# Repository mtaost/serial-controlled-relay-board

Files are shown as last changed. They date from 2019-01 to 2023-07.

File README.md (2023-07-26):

# Serial Controlled Relay Board
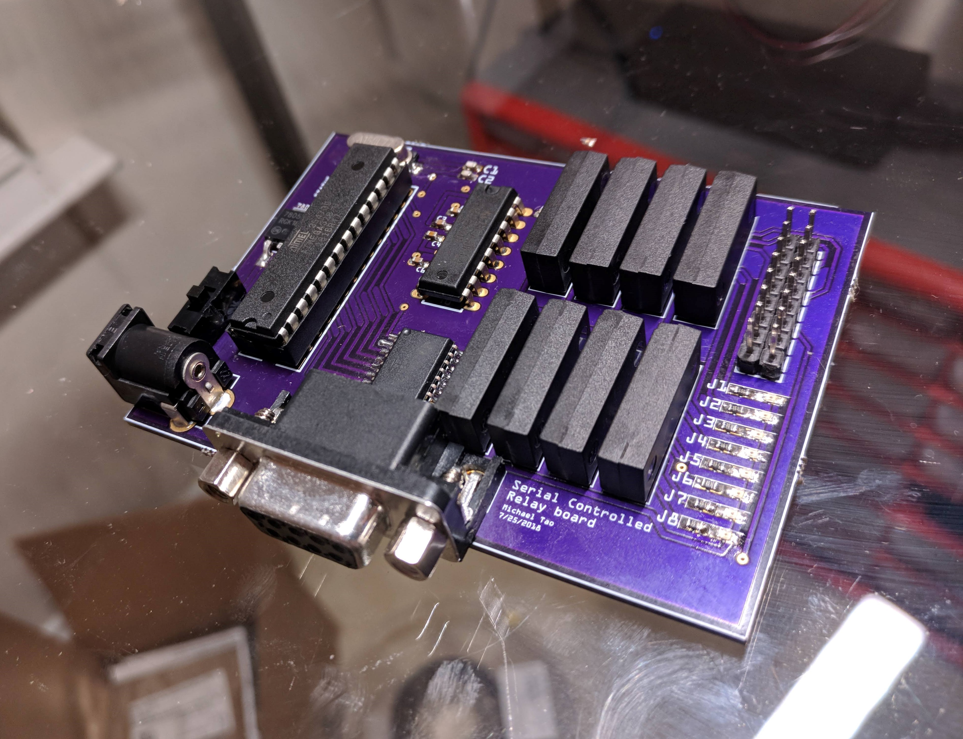
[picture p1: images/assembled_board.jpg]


This device is a command line controlled device capable of controlling 8 low current reed relays. This was a commissioned project which was meant to help with testing of computer systems which frequently needed their boot configurations switched through hardware jumpers. The normal procedure involved shutting down the system remotely, then walking over to the lab to remove the system from the chassis and manually setting jumpers which looked something like this: 



Doing this not only was time consuming, but also introduced the system to risk of damage from physical wear and tear, and ESD dangers. 
With the SCRB, one can remotely control the state of whatever jumpers are on the board through a command line interface. For example: 

    $ Serial Relay Controller Ready
    
    $ status
	    J1:		OFF
	    J2:		OFF
	    J3:		OFF
	    J4:		OFF
	    J5:		OFF
	    J6:		OFF
	    J7:		OFF
	    J8:		OFF
	    
	$ set J1 on
	J1: OFF -> ON
After this series of commands, the jumper in position J1 will now be connected, simulating a connected jumper. The board also supports renaming jumpers: 

    $ rename J1 write_protect
    J1 renamed to: write_protect
    $ status
    	write_protect:		ON
	    J2:		OFF
	    J3:		OFF
	    J4:		OFF
	    J5:		OFF
	    J6:		OFF
	    J7:		OFF
	    J8:		OFF

This could also be used for other, low current/voltage switching applications. 
## Circuit design
The SCRB uses a simple ATmega 328PU MCU as its brains. This is the same microprocessor used on the Arduino Uno which I happened to have a lot of which made it easy to prototype and test. Communication with the serial connection is managed through a MAX232 level converter which is necessary to lower the higher voltage levels of the RS232 standard (-13 to +13 volts) to a more TTL friendly 0-5v. To handle the switching of the relays, a Darlington transistor array ensures that the microprocessor is not damaged by the inductive kickback of the relays (however small it might be). 
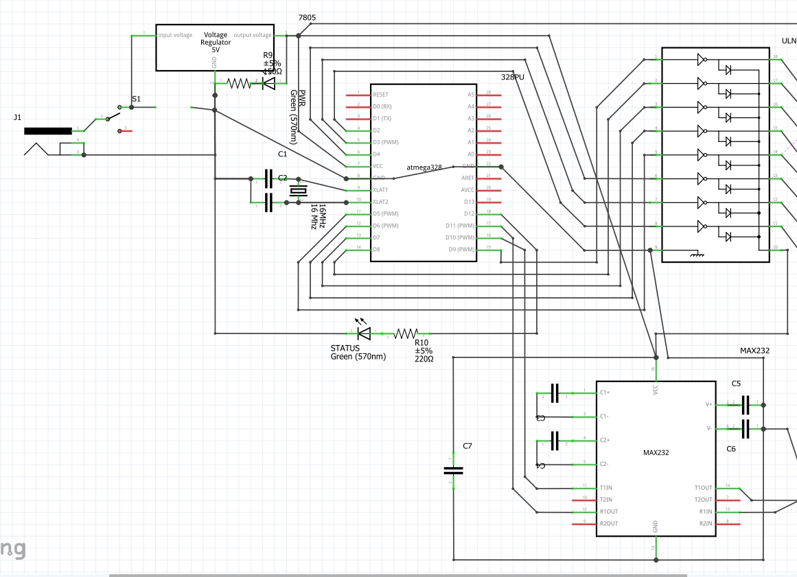
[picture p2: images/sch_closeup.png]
Schematic of processing side of SCRB


The relays used are 500mAh, 200VDC reed relays. In their application as jumper connectors, they really only need to switch 3.3VDC and negligible current but these were the most suitable relays I could find. An array of LEDs lets you know when each relay is working. 

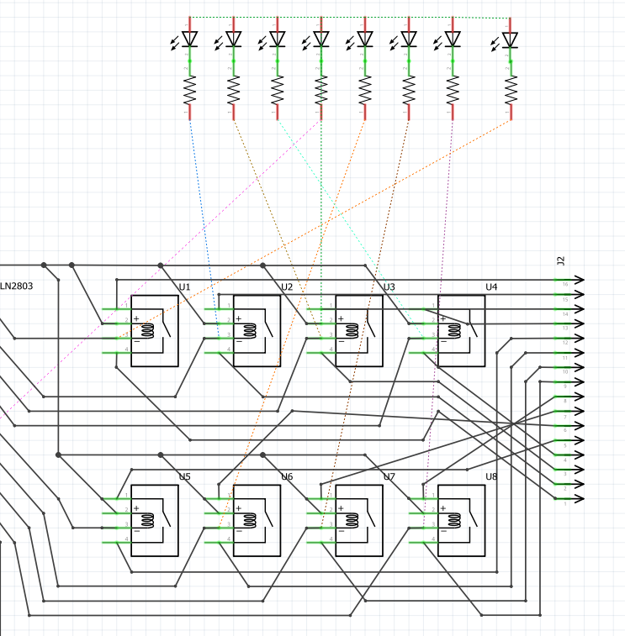
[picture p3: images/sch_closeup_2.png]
Schematic of relay side of SCRB


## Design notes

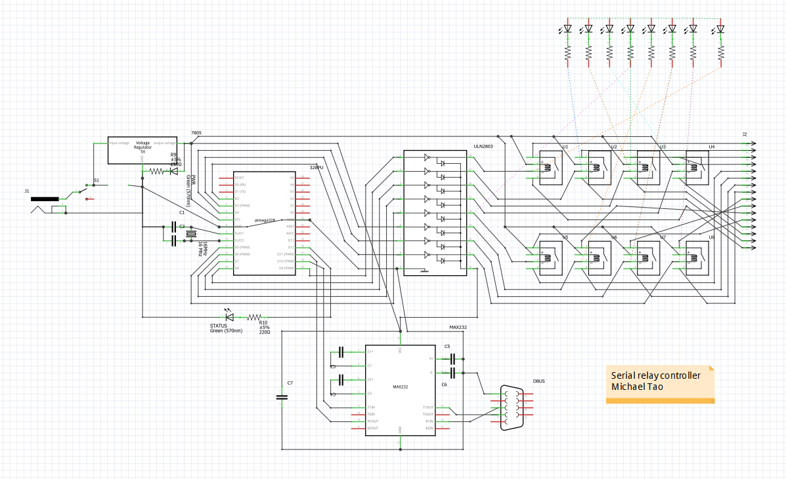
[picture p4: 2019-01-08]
images/sch_overview.png

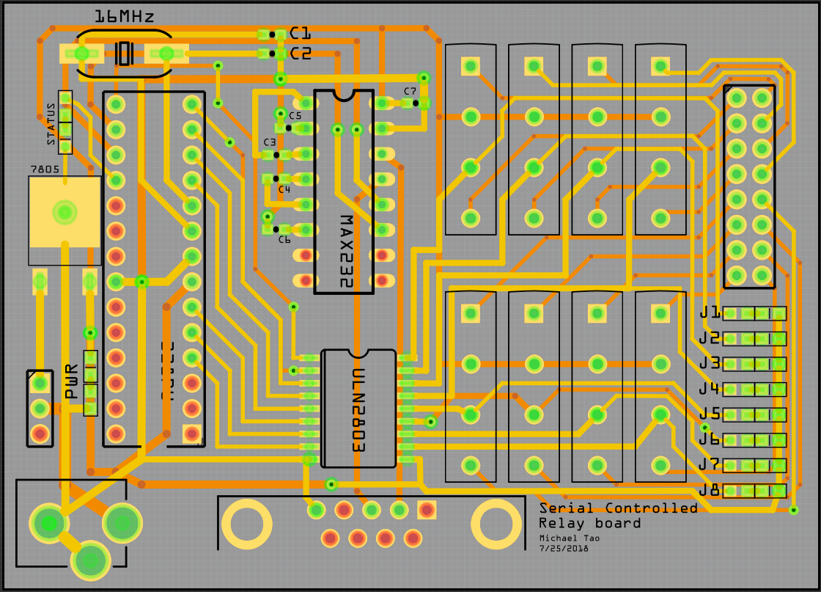
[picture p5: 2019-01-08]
images/pcb_overview.png

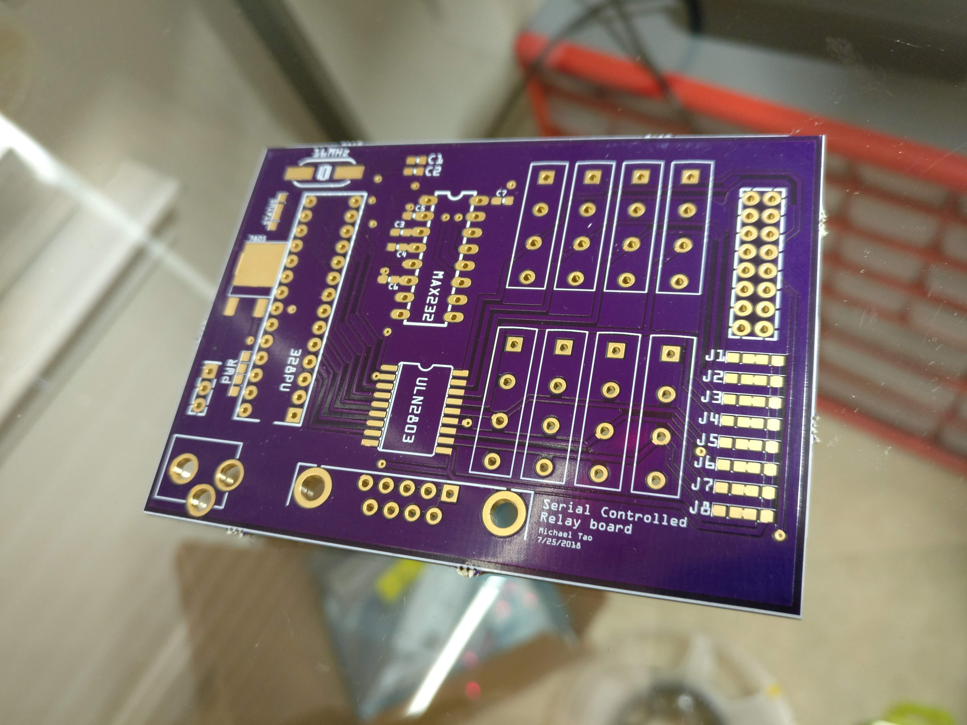
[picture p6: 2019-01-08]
images/pcb_top.jpg

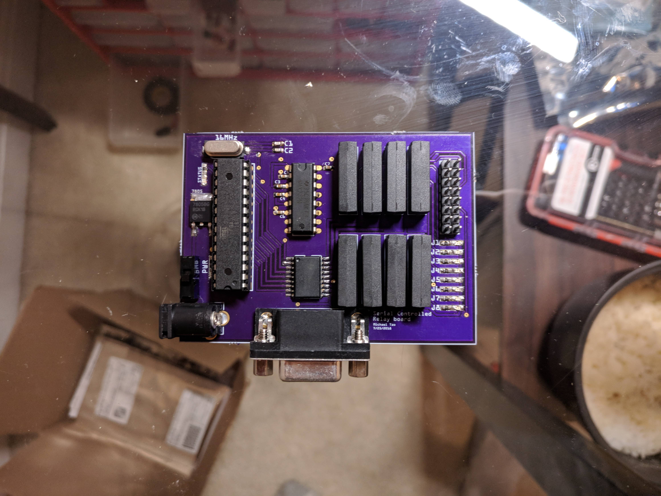
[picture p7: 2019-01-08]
images/top_view.jpg

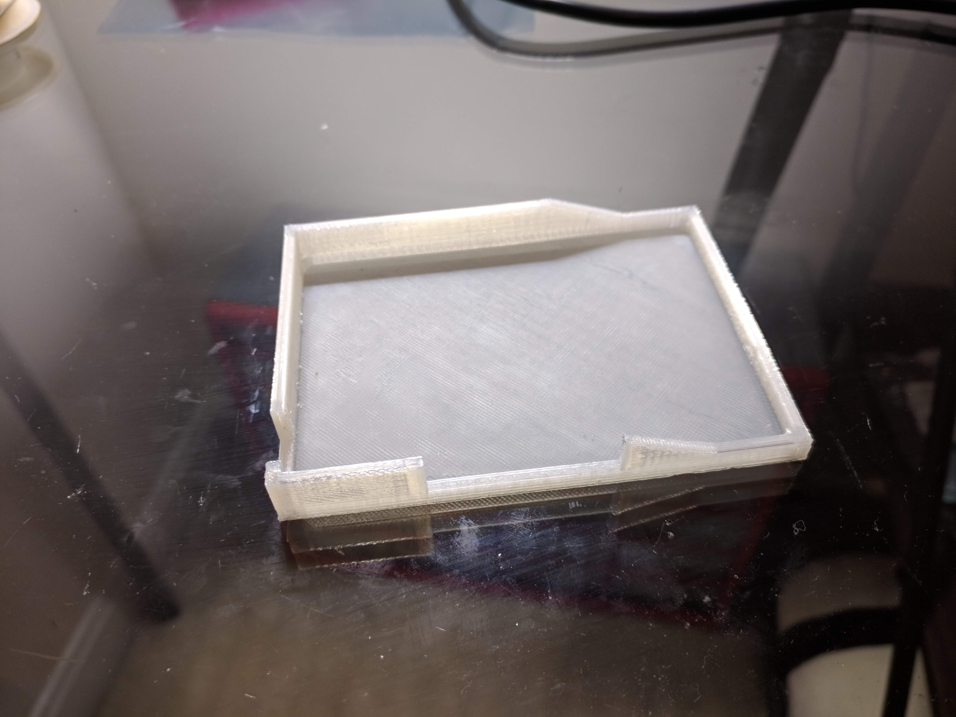
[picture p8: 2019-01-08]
images/pla_enclosure.jpg

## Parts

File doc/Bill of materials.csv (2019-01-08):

Manufacturer | Digi-Key Part Number | Customer Reference | Quantity | Unit Price | Extended Price | Description
Panasonic Electronic Components | P150HCT-ND | LED resistors | 8 | 0.1 | $0.80 | RES SMD 150 OHM 1% 1/10W 0603
ON Semiconductor | MC7805BDTRKGOSCT-ND | 5V power regulator | 1 | 0.64 | $0.64 | IC REG LINEAR 5V 1A DPAK
On Shore Technology Inc. | ED3050-5-ND | MCU socket | 1 | 0.34 | $0.34 | CONN IC DIP SOCKET 28POS TIN
Abracon LLC | 535-10226-1-ND | MCU Crystal | 1 | 0.27 | $0.27 | CRYSTAL 16.0000MHZ 18PF SMD
E-Switch | EG1903-ND | Power switch | 1 | 0.61 | $0.61 | SWITCH SLIDE SPDT 200MA 30V
CUI Inc. | CP-002A-ND | Power jack | 1 | 0.63 | $0.63 | CONN PWR JACK 2X5.5MM SOLDER
Murata Electronics North America | 490-1411-1-ND |  | 2 | 0.11 | $0.22 | CAP CER 22PF 50V C0G/NP0 0603
Texas Instruments | 296-15777-1-ND |  | 1 | 1.53 | $1.53 | TRANS 8NPN DARL 50V 0.5A 18SO
Coto Technology | 306-1063-ND | Reed relays | 8 | 1.43 | $11.44 | RELAY REED SPST 500MA 5V
Microchip Technology | ATMEGA328-PU-ND |  | 1 | 1.96 | $1.96 | IC MCU 8BIT 32KB FLASH 28DIP
Texas Instruments | 296-1402-5-ND |  | 1 | 1.49 | $1.49 | IC DUAL EIA-232 DRVR/RCVR 16-DIP
Assmann WSW Components | AE10921-ND |  | 1 | 0.77 | $0.77 | CONN D-SUB RCPT 9POS R/A SOLDER
Lite-On Inc. | 160-1446-1-ND |  | 8 | 0.29 | $2.32 | LED GREEN CLEAR SMD
Samsung Electro-Mechanics | 1276-1102-1-ND |  | 4 | 0.1 | $0.40 | CAP CER 1UF 25V X5R 0603

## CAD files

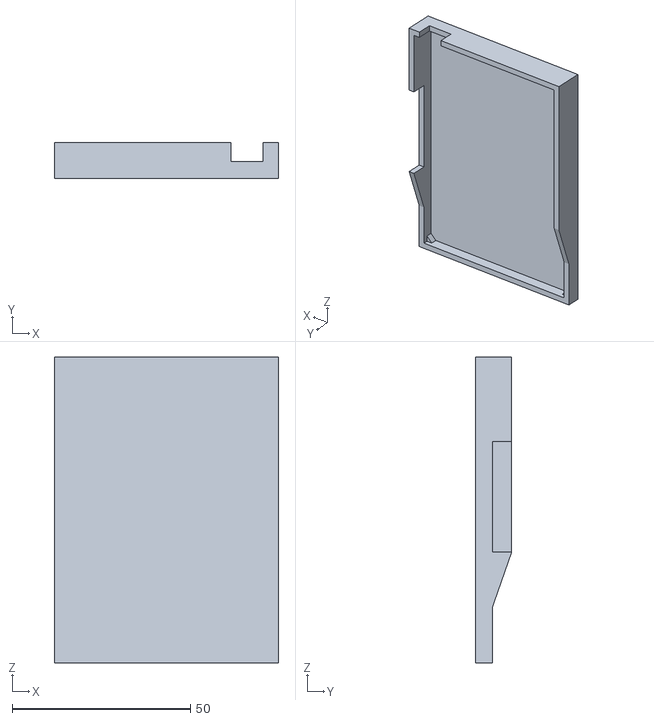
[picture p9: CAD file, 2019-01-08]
3D_print_enclosure/Enclosure.stl
62.8 x 10.2 x 85.8

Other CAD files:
3D_print_enclosure/Enclosure.ipt

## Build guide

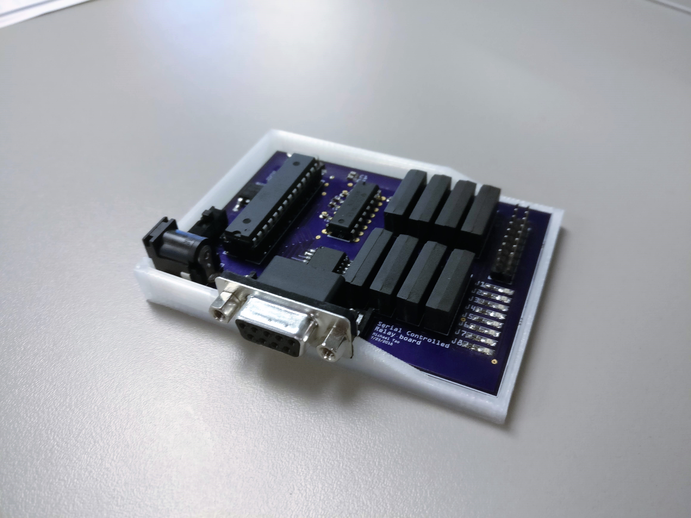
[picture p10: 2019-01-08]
images/assembled_board_in_enclosure.jpg

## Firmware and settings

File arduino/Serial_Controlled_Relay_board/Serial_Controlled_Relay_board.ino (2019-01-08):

/*
   Serial Relay Controller
   Author: Michael Tao
   Date: 8/9/2018

   Credit to https://github.com/kroimon/Arduino-SerialCommand for inspiration for serial command line interpreter
*/

#include <SoftwareSerial.h>

#define NUM_COMMANDS 5
#define BUFFER_SIZE 64
#define MAX_COMMAND_SIZE 16
#define MAX_JUMPER_NAME_SIZE 16
#define NUM_JUMPERS 8
#define BAUD_RATE 115200
#define PROMPT "# "
#define DELIMINATOR " "

// Pin definitions
// These are specific to how the board is routed so they're here for reference
#define J1_PIN 9
#define J2_PIN 8
#define J3_PIN 7
#define J4_PIN 6
#define J5_PIN 5
#define J6_PIN 4
#define J7_PIN 3
#define J8_PIN 2
#define TX 10
#define RX 11
#define STATUS_LED 12

SoftwareSerial softSerial = SoftwareSerial(RX, TX);
// Buffer for storing input so far
char buffer[BUFFER_SIZE];
int buffPos = 0;

// Counter to newest position in command list
int numCommands = 0;

// Struct to keep track of command names and their function call
struct Command {
  char name[MAX_COMMAND_SIZE];
  void (*function)();
};
Command commandList[NUM_COMMANDS];

// Struct to keep track of jumper names and their state
struct Jumper {
  char name[MAX_JUMPER_NAME_SIZE];
  int pin;
  boolean state = false; // true for on, false for off
};
Jumper jumperList[NUM_JUMPERS];

// Flag to keep track of whether we've sent the prompt or not
boolean prompt_sent;

// Terminal character (generally set to \r)
char term;

// Something for strtok_r to remember what it last tokenized. See strtok_r documentation for details
char* last;


void setup() {
  pinMode(STATUS_LED, OUTPUT);
  pinMode(J1_PIN, OUTPUT);
  pinMode(J2_PIN, OUTPUT);
  pinMode(J3_PIN, OUTPUT);
  pinMode(J4_PIN, OUTPUT);
  pinMode(J5_PIN, OUTPUT);
  pinMode(J6_PIN, OUTPUT);
  pinMode(J7_PIN, OUTPUT);
  pinMode(J8_PIN, OUTPUT);

  softSerial.begin(BAUD_RATE);

  // Setup callbacks for commands
  addCommand("help", help);
  addCommand("set", set);
  addCommand("status", status);
  addCommand("rename", rename);
  addCommand("reset", reset);

  softSerial.println('\f');
  softSerial.println("Serial Relay Controller ready");
  blink(3);

  // Set jumper values to their defaults
  defaultJumperInit();

  // Establish the buffer and other strings reader needs to function
  initReader();
}

// In the loop, we send the prompt if it hasn't been sent, and then just call readSerial() to wait for user input
void loop() {
  if (!prompt_sent) {
    softSerial.print(PROMPT);
    prompt_sent = true;
    blink(1);
  }
  readSerial();
}


// Just prints user manual
void help() {
  softSerial.println("Available commands: ");
  softSerial.println("   set jumper_name|all {on|off}");
  softSerial.println("       Sets jumper with name 'jumper_name' on or off. If jumper name is 'all', will set all jumpers.\n");
  softSerial.println("   status [jumper_name]");
  softSerial.println("       Shows whether jumper is on or off. If no jumper or 'all' is provided, will display all jumper statuses\n");
  softSerial.println("   rename old_name new_name");
  softSerial.println("       Renames a jumper. Cannot use an existing name or 'all'\n");
  softSerial.println("   reset");
  softSerial.println("       Resets jumper names back to defaults. Sets all jumpers to off.\n");
  softSerial.println("   help");
  softSerial.println("       Displays this help dialogue.");
}


// Blink method for visual confirmation that things are working. Not really used though
void blink(int i) {
  while (i > 0) {
    digitalWrite(STATUS_LED, HIGH);
    delay(100);
    digitalWrite(STATUS_LED, LOW);
    delay(100);
    i--;
  }
}

// Sets a jumper to on or off. This is called after the "set" part of the command has been consumed, so jumperName and state are obtained
// by calling nextToken() which will consume the next two tokens (if there are any)
void set() {
  char *jumperName = nextToken();
  char *state = nextToken();
  int jumper_index;
  boolean setTo;
  boolean lastState;

  if (jumperName == NULL) {
    softSerial.println("Missing jumper");
    softSerial.println("Syntax: set jumper {on/off}");
    softSerial.println("        set all    {on/off}");
    return;
  }

  if (state == NULL) {
    softSerial.println("Please specify a value for state");
    softSerial.println("Syntax: set jumper {on/off}");
    softSerial.println("        set all    {on/off}");
    return;
  }

  if (strcmp(state, "on") == 0) {
    setTo = true;
  }
  else if (strcmp(state, "off") == 0) {
    setTo = false;
  }
  // If we don't match on or off, invalid state
  else {
    softSerial.println("Please specify either 'on' or 'off'");
    return;
  }

  // Get the index of the jumper we're looking for
  jumper_index = findJumper(jumperName);

  // If we don't find the jumper name
  if (jumper_index == -1) {
    // If jumper name is all (case insensitive), loop through all jumpers and set them
    if (strcmp(strlwr(jumperName), "all") == 0) {
      for (int i = 0; i < NUM_JUMPERS; i++) {
        Jumper j = jumperList[i];
        lastState = j.state;
        j.state = setTo;
        jumperList[i] = j;

        softSerial.print(j.name);
        softSerial.print("\t: ");
        lastState ? softSerial.print("ON ") : softSerial.print("OFF");
        softSerial.print(" -> ");
        setTo ? softSerial.println("ON") : softSerial.println("OFF");

        updateState(i);
      }
    }

    // Otherwise for jumper_index == -1, jumper is invalid
    else {
      softSerial.print(jumperName);
      softSerial.println(" is not a valid jumper");
      softSerial.println("Use 'status' for a list of valid jumpers");
    }
  }

  // If we have a jumper index, set the jumper
  else {
    Jumper j = jumperList[jumper_index];
    lastState = j.state;
    j.state = setTo;
    jumperList[jumper_index] = j;

    softSerial.print(jumperName);
    softSerial.print(": ");
    lastState ? softSerial.print("ON") : softSerial.print("OFF");
    softSerial.print(" -> ");
    setTo ? softSerial.println("ON") : softSerial.println("OFF");

    updateState(jumper_index);
  }
}

// Renames a jumper, cannot name a jumper any variation of 'all' to avoid confusion with the keyword used in 'set all on/off'
void rename() {
  char *oldName = nextToken();
  char *newName = nextToken();
  int jumperIndex;

  if (oldName == NULL) {
    softSerial.println("Missing jumper_name");
    softSerial.println("Syntax: rename jumper_name new_name");
    return;
  }
  if (newName == NULL) {
    softSerial.println("Missing new_name");
    softSerial.println("Syntax: rename jumper_name new_name");
    return;
  }

  // Do not allow a jumper to be named "ALL"
  if (strcmp(newName, "all") == 0) {
    softSerial.println("Jumper cannot be named 'all'");
    return;
  }

  jumperIndex = findJumper(oldName);

  // Invalid jumper option
  if (jumperIndex == -1) {
    softSerial.print(oldName);
    softSerial.println(" is not a valid jumper");
  }

  // New jumper name already exists
  else if (findJumper(newName) != -1) {
    softSerial.print(newName);
    softSerial.println(" already exists! Please pick a different name.");
  }

  // Otherwise, rename jumper
  else {
    strcpy(jumperList[jumperIndex].name, newName);
    softSerial.print(oldName);
    softSerial.print(" renamed to: ");
    softSerial.println(newName);
  }
}

// Call init again and reset jumpers to their starting values
void reset() {
  defaultJumperInit();
  softSerial.println("Jumper names reset to default values");
  softSerial.println("All jumpers now off");
}

// Shows the status of a jumper, or all jumpers
void status() {
  char *jumperName = nextToken();
  int jumperIndex;
  boolean state;

  // If no argument is provided, or the argument is all, list all jumpers
  if (jumperName == NULL || strcmp(jumperName, "all") == 0) {
    char *name;
    for (int i = 0; i < NUM_JUMPERS; i++) {
      state = jumperList[i].state;
      name = jumperList[i].name;
      softSerial.print(name);
      softSerial.print("\t:");
      state ? softSerial.println("ON") : softSerial.println("OFF");
    }
    return;
  }

  jumperIndex = findJumper(jumperName);

  // Invalid jumper option
  if (jumperIndex == -1) {
    softSerial.print(jumperName);
    softSerial.println(" is not a valid jumper");
  }

  else {
    state = jumperList[jumperIndex].state;
    softSerial.print(jumperName);
    softSerial.print("\t:");
    state ? softSerial.println("ON") : softSerial.println("OFF");
  }
}

// Applies state of jumper to respective digital pin
// Assumes jumperIndex is valid
void updateState(int jumperIndex) {
  boolean state;
  String str;
  int pin;

  state = jumperList[jumperIndex].state;
  pin = jumperList[jumperIndex].pin;
  
//  softSerial.print("Wrote ");
//  str = state ? "ON" : "OFF";
//  softSerial.print(str);
//  softSerial.print(" to pin ");
//  softSerial.println(pin);
  
  digitalWrite(pin, state);
}

// Input name of jumper, returns index of jumper in jumperList
// Returns -1 if not found
int findJumper(char *jumperName) {
  int curr_jumper;
  boolean found_jumper = false;
  for (curr_jumper = 0; curr_jumper < NUM_JUMPERS; curr_jumper++) {
    if (strcmp(jumperName, jumperList[curr_jumper].name) == 0) {
      found_jumper = true;
      break;
    }
  }
  return found_jumper ? curr_jumper : -1;
}

void addCommand(const char *command, void (*function)()) {
  strncpy(commandList[numCommands].name, command, MAX_COMMAND_SIZE);
  commandList[numCommands].function = function;
  numCommands++;
}

void readSerial() {
  while (softSerial.available() > 0) {
    char nextChar;
    char* token;
    boolean matched = false;
    nextChar = softSerial.read();

    // If the next character matches the term (probably '\r'), process command
    if (nextChar == term) {
      prompt_sent = false;
      softSerial.println();
      buffPos = 0;
      // Tokenize what we have so far and get the first token separated by deliminator (probably " ")
      token = strtok_r(buffer, DELIMINATOR, &last);
      // Empty string input, ignore
      if (token == NULL) {
        return;
      }
      else {
        for (int i = 0; i < NUM_COMMANDS; i++) {
          if (strcmp(token, commandList[i].name) == 0) {
            (*commandList[i].function)();
            softSerial.println();
            clearBuffer();
            matched = true;
            break;
          }
        }
      }
      if (matched == false) {
        softSerial.print('\r');
        softSerial.print(buffer);
        softSerial.println(" is not a valid command");
        softSerial.println("Enter 'help' for available commands\n");
        clearBuffer();
      }
    }

    // When user presses backspace, delete character off buffer and reflect change in terminal
    if (nextChar == '\b') {
      if (buffPos > 0) {
        buffer[--buffPos] = '\0';
        softSerial.print("\b \b");
      }
    }

    // If the input character is printable, add it to the buffer and send character to terminal
    if (isprint(nextChar)) {
      if (buffPos < BUFFER_SIZE - 1) { // Prevent overflow and clobbering memory
        buffer[buffPos++] = nextChar;
        buffer[buffPos] = '\0';
        softSerial.print(nextChar);
      }
    }
  }
}

// Initialize some starting values
void initReader() {
  prompt_sent = false;
  term = '\r';
  memset(buffer, 0, BUFFER_SIZE);
}

// Reset the buffer, easiest thing to do is to set first char in array to null terminator \0
void clearBuffer() {
  buffPos = 0;
  buffer[buffPos] = '\0';
}

// Consumes the next token in the command. This works since strtok_r remembers its last tokenized string if it is passed in NULL
char *nextToken() {
  char *nextToken;
  nextToken = strtok_r(NULL, " ", &last);
  return nextToken;
}

// Initialize jumper names to default values. A little hard coded 
void defaultJumperInit() {
  char *names[8] = {"J1", "J2", "J3", "J4", "J5", "J6", "J7", "J8"};
  int pins[8] = {J1_PIN, J2_PIN, J3_PIN, J4_PIN, J5_PIN, J6_PIN, J7_PIN, J8_PIN};
  for (int i = 0; i < NUM_JUMPERS; i++) {
    strcpy(jumperList[i].name, names[i]);
    Jumper j = jumperList[i];
    j.state = false;
    j.pin = pins[i];
    jumperList[i] = j;
    updateState(i);
  }
}
